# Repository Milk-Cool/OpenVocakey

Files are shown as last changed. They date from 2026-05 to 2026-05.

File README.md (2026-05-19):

# OpenVocakey
An open-source ESP32-based vocal synthesis keyboard

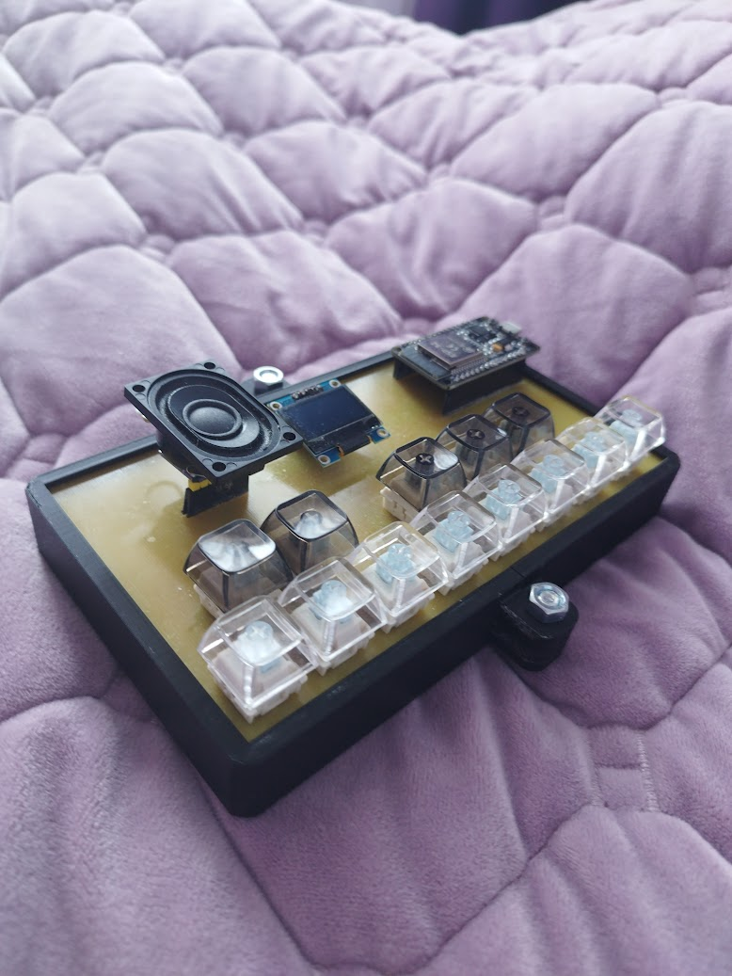
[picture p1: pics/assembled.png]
Assembled keyboard


## What is this?
This is exactly what it sounds like -- a DIY open-source keyboard capable of producing human-like speech in the form of singing. Yes, just like VOCALOID -- except it is live, so it would be closer to [Pocket Miku](https://youtu.be/Uk6hSK1DDR4) or the [VOCALOID Keytar](https://en.wikipedia.org/wiki/Vocaloid_Keyboard).

### What is this based on?
It uses [espeak-ng](https://github.com/espeak-ng/espeak-ng) at its core, with the wrapper being [BackgroundAudio](https://github.com/earlephilhower/BackgroundAudio) and the wrapper wrapper being `tts.cpp`. This means that the voices are actually very customizable! You can use formant settings to adjust the voice to your liking and then upload it to the device.

## How do I use it?
You can buy a [Cardputer](https://shop.m5stack.com/products/m5stack-cardputer-adv-version-esp32-s3) if you wanna check the project out, or make a keyboard of your own with the provided gerber and KiCad files. Then, you can upload songs and files using the [online tool](https://milk-cool.github.io/OpenVocakey/) (works best with Chromium-based browsers).

### Song format
A song is just a text file containing Japanese characters (hiragana or katakana but NOT kanji), with each syllable on its own line, for example:
```
き
ら
き
ら
ひ
か
る
```

You can also add ending syllables after a base syllable, separated by a comma (will not be stretched):
```
こ,い
```

> Note: you can input more than one syllable on one line, but then the vowel stretch won't work properly.

### Voice format
This is just an espeak-ng voice, but without the `pitch` and `language` fields (those are added automatically). See [the documentation for espeak-ng](https://github.com/espeak-ng/espeak-ng/blob/master/docs/voices.md) for specific instructions on how to create a voice.

### Assembling the board
If you decided to make your own keyboard, first of all, you'd have to order a two-layer PCB. This is because one of the traces (yes, just one!) is on the other side of the PCB. Then, once it arrives, you have to solder MX-Cherry style keyboard switches into the holes on the bottom of the board (and add keycaps to your liking) and solder on female 2.54mm headers everywhere else. Then, you can insert a 30-pin ESP32-WROOM board into the double headers (with the USB port facing outwards), an i2c SSD1306 display into the middle headers (facing inwards) and a MAX98357a i2s audio amplifier into the remaining headers (facing outwards; don't forget to connect a speaker!!). Also don't forget to solder on the 10K resistors for pull-up below the ESP32. Then you can print out the case (`case/`), slide the board inside and screw it down on the sides with M6x20 bolts. Then you'd have to upload the firmware to the ESP32 and you're done!!

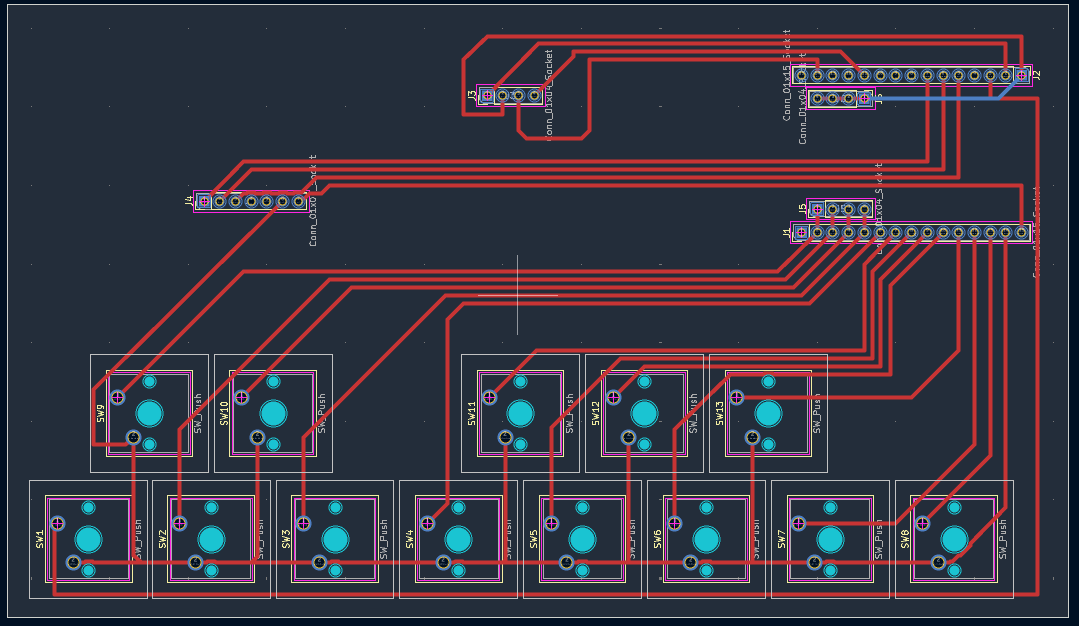
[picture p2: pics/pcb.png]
PCB


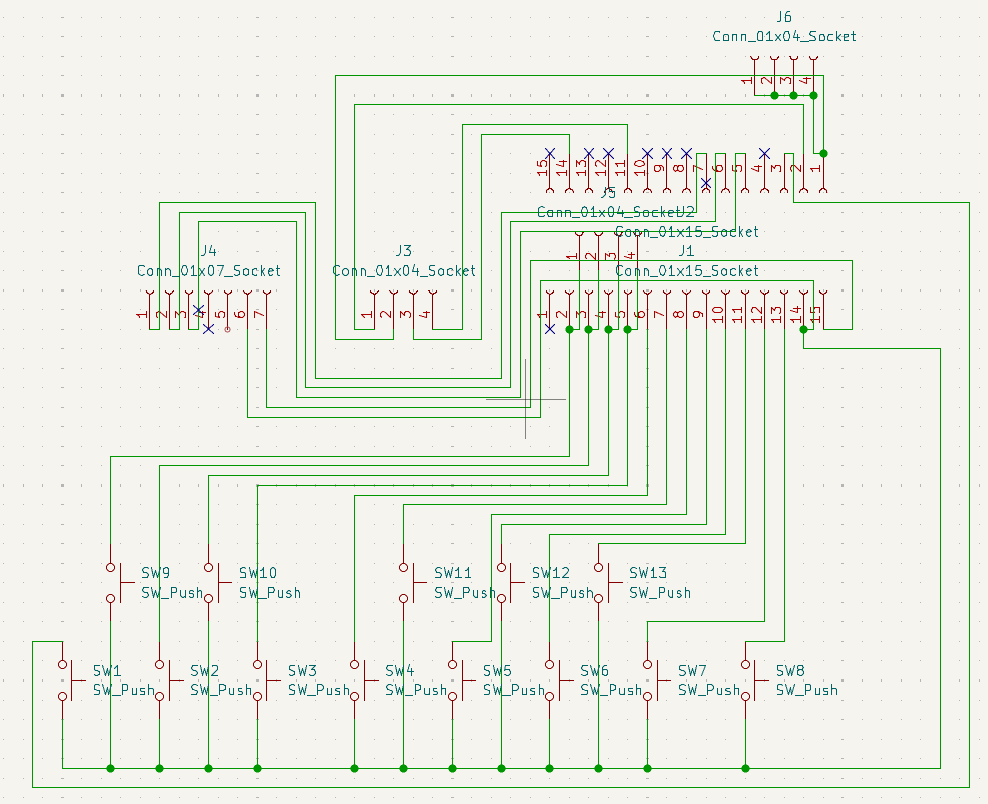
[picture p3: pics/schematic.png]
Schematic


> Note: see `bom.csv` for the Bill of Materials.

### Navigating the menus
You can press BOOT/G0 on your board to enter the menu. From there, you can press the two leftmost white buttons to move left or right, and the rightmost two white buttons for cancelling and confirming your actions (e. g. entering a submenu and then confirming the volume change using the rightmost button). You can also press G0 again to leave the menu.

Go on, play around with the menus and see what you can customize!!

> Note: most settings are discarded upon reboot.

### Using the website
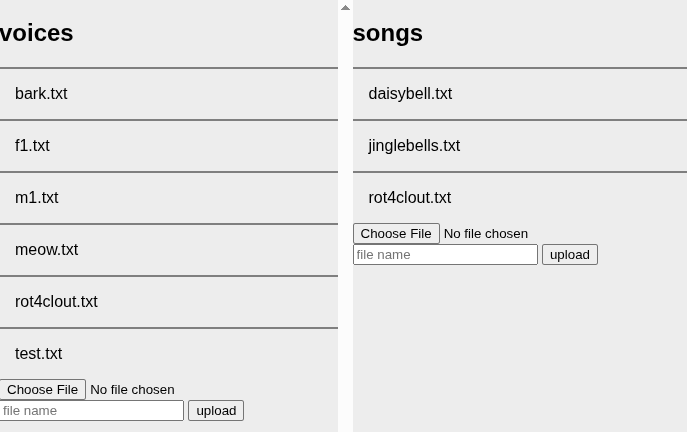
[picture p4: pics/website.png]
Website screenshot


You can use the [online tool](https://milk-cool.github.io/OpenVocakey/) to manage the files on your OpenVocakey. First, click "Connect" in the corner and select your board. Then, you can download the already existing files by clicking on them, or upload new files by first selecting the file, then giving it a name and then clicking "upload".

> Note: that **WILL** overwrite the file! Be careful.

## Why does this exist?
I was always fascinated by vocaloids and the two aforementioned products in paticular, hence I decided to make this. Those can be hard to get and rather unaffordable, especially in non-first-world countries, therefore I think people might find this useful.

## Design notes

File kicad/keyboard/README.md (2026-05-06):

Not my footprint!! See https://github.com/KiCad/kicad-footprints/blob/master/Button_Switch_Keyboard.pretty/SW_Cherry_MX_1.00u_PCB.kicad_mod

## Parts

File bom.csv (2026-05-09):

Product name | Product link | Product cost | Product amount | Notes
10 kOhm resistor | https://aliexpress.com/item/1005011886443911.html | $0.05 | 4 | Link leads to listing with 20 pieces available only. Price specified per unit; it is $0.91 to buy 20 pcs.
MX Cherry keyboard switches 1.00u | https://www.aliexpress.us/item/3256804049630074.html | $18.69 | 13 | Both 3-pin and 5-pin switches are acceptable.
White keycaps | https://www.aliexpress.us/item/3256808845306164.html | $1.76 | 8 | Link leads to listing with 20 pieces available only. Price specified per unit; it is $4.39 to buy 20 pcs.
White keycaps | https://www.aliexpress.us/item/3256808845306164.html | $1.10 | 5 | Link leads to listing with 20 pieces available only. Price specified per unit; it is $4.45 to buy 20 pcs.
ESP32 DevKitV1 | https://www.aliexpress.us/item/3256809960927549.html | $5.79 | 1
SSD1306 i2c OLED display | https://www.aliexpress.us/item/3256808099809825.html | $7.05 | 1 | Link leads to listing with multiple options. White i2c is recommended.
MAX98357A i2s audio amplifier | https://www.aliexpress.us/item/3256806817487911.html | $4.53 | 1
3W 4Ohm speaker | https://www.aliexpress.us/item/3256809207290559.html | $3.46 | 1
1x4 pin headers | https://nl.aliexpress.com/item/4001198421663.html | $0.17 | 1 | Link leads to listing with 10 pieces available only. Price specified per unit; it is $1.65 to buy 10 pcs.
1x7 pin headers | https://nl.aliexpress.com/item/4001198421663.html | $0.18 | 1 | Link leads to listing with 10 pieces available only. Price specified per unit; it is $1.79 to buy 10 pcs.
1x15 pin headers | https://nl.aliexpress.com/item/4001198421663.html | $0.21 | 2 | Link leads to listing with 10 pieces available only. Price specified per unit; it is $2.14 to buy 10 pcs.
Total |  | $42.99

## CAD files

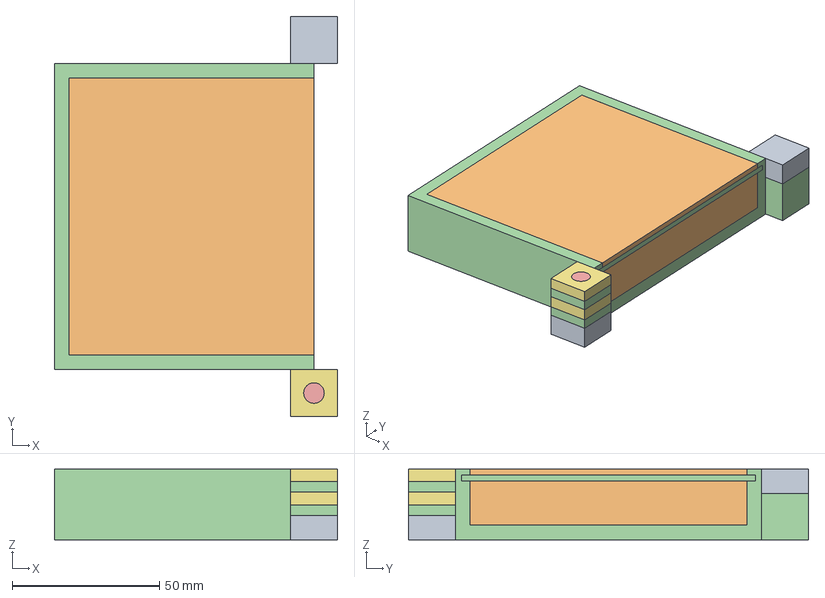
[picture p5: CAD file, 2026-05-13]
case/openvocakey.step
96.2 x 136.1 x 24.0 mm
X-axis x 3
XY-plane x 3
Sketch

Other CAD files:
case/openvocakey.FCStd
case/openvocakey.obj

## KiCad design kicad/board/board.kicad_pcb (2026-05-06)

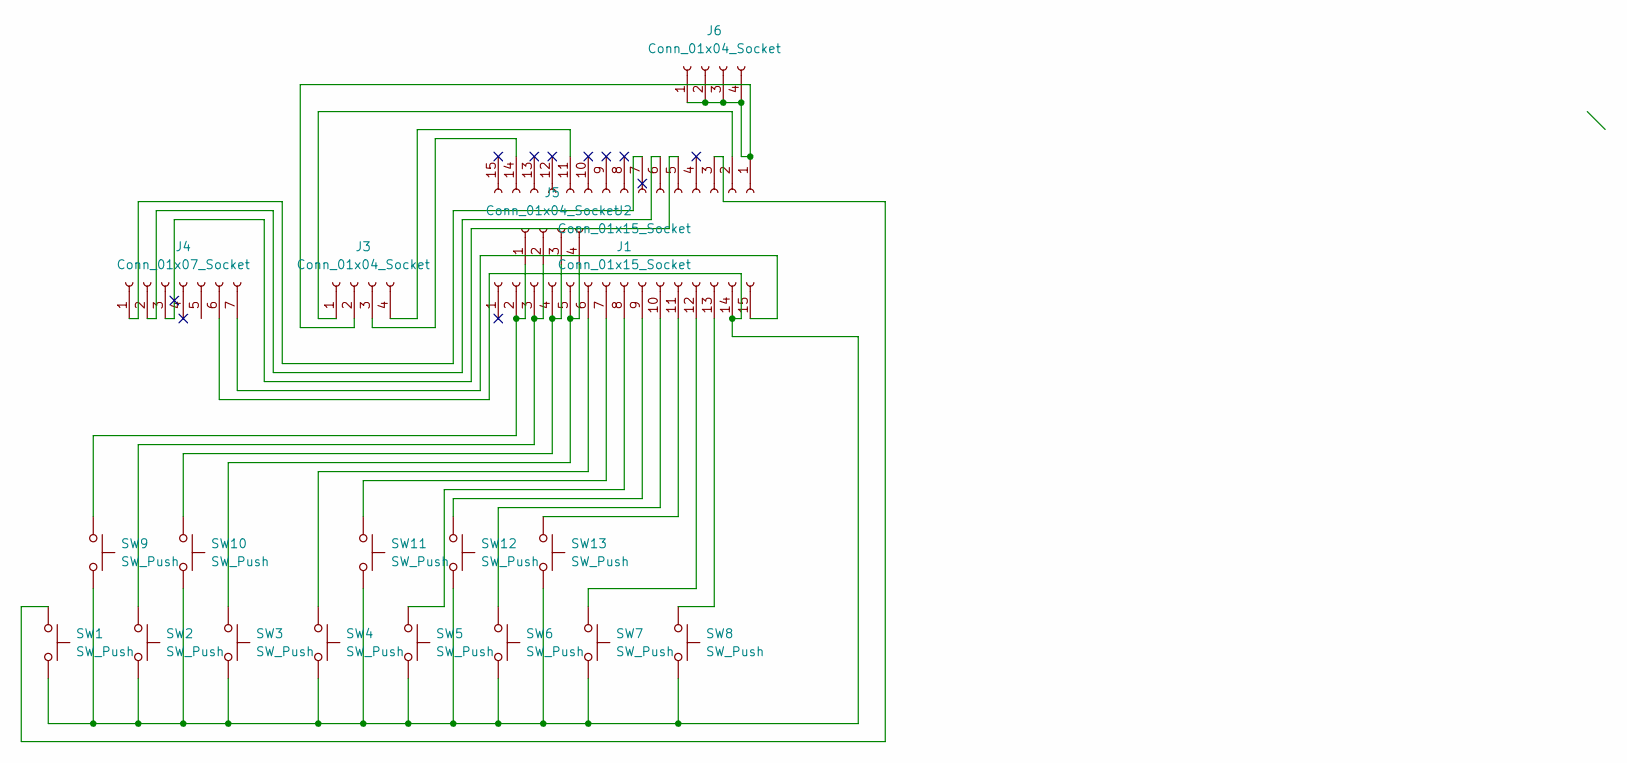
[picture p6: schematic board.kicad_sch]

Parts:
J1, J2: Conn_01x15_Socket; PinHeader_1x15_P2.54mm_Vertical
J3, J5, J6: Conn_01x04_Socket; PinHeader_1x04_P2.54mm_Vertical
J4: Conn_01x07_Socket; PinHeader_1x07_P2.54mm_Vertical
SW1, SW2, SW3, SW4, SW5, SW6, SW7, SW8, SW9, SW10, SW11, SW12, SW13: SW_Push; SW_Cherry_MX_1.00u_PCB

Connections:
unnamed: J1.2, J5.1, SW9.1
unnamed: J1.3, J5.2, SW2.1
unnamed: J1.4, J5.3, SW10.1
unnamed: J1.5, J5.4, SW3.1
unnamed: J1.6, SW4.1
unnamed: J1.7, SW11.1
unnamed: J1.8, SW5.1
unnamed: J1.9, SW12.1
unnamed: J1.10, SW6.1
unnamed: J1.11, SW13.1
unnamed: J1.12, SW7.1
unnamed: J1.13, SW8.1
unnamed: J1.14, J4.6, SW1.2, SW2.2, SW3.2, SW4.2, SW5.2, SW6.2, SW7.2, SW8.2, SW9.2, SW10.2, SW11.2, SW12.2, SW13.2
unnamed: J1.15, J4.7
unnamed: J2.1, J3.2, J6.1, J6.2, J6.3, J6.4
unnamed: J2.2, J3.1
unnamed: J2.3, SW1.1
unnamed: J2.5, J4.3
unnamed: J2.6, J4.2
unnamed: J2.7, J4.1
unnamed: J2.11, J3.4
unnamed: J2.14, J3.3

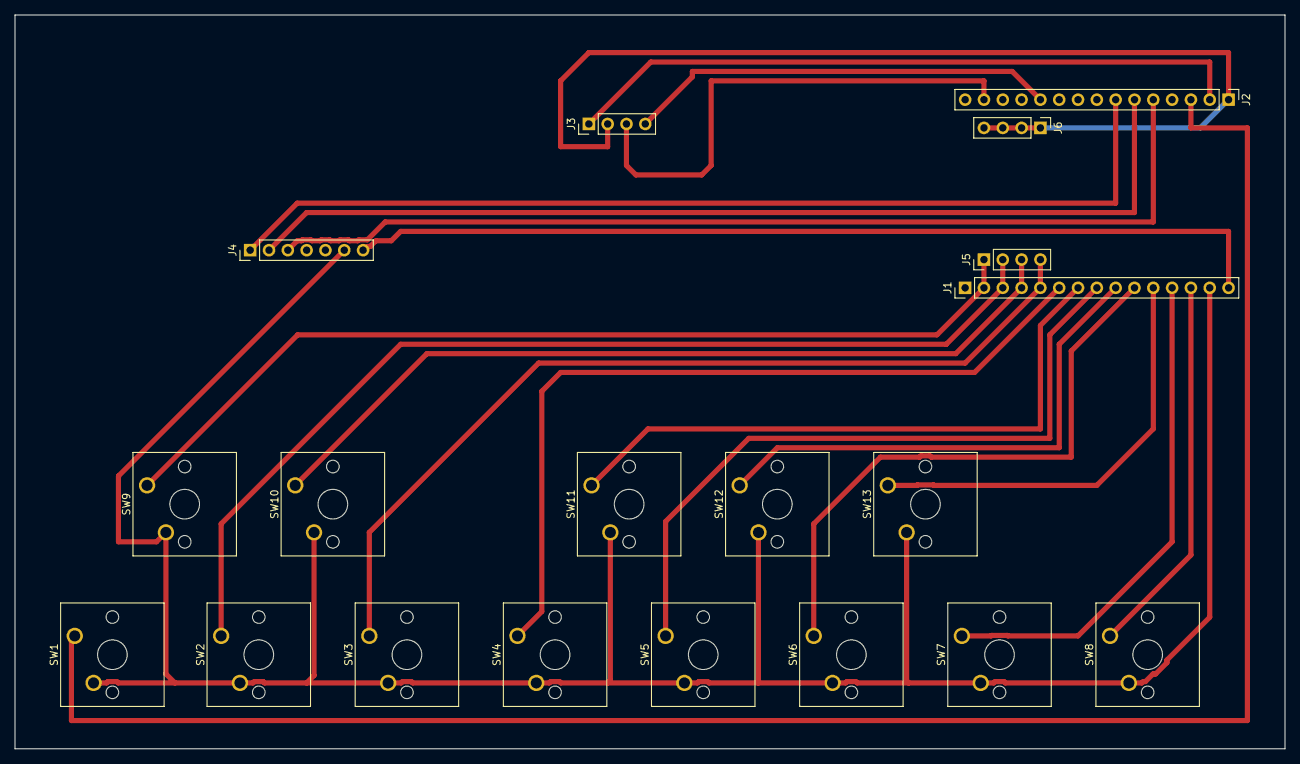
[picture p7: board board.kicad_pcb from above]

Board: 2 copper layers, 171.4 x 99.1 mm, 19 parts (0 on the bottom side), 22 nets.

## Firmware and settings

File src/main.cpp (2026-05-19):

#include <Arduino.h>
#ifdef CARDPUTER
#include <M5Cardputer.h>
#else
// #include "font.h"
#endif
#include "tts.h"
#include "pitch.h"
#include "cvt.h"
#include <LittleFS.h>
#include <vector>
#include <utility>
#include "input.h"
#include "gfx.h"

static unsigned i = 0;
static std::vector<std::pair<String, String>> g_song = {
    { "き", "" }, { "ら", "" }, { "き", "" }, { "ら", "" }, { "ひ", "" }, { "か", "" }, { "る", "" },
    { "お", "" }, { "そ", "" }, { "ら", "" }, { "の", "" }, { "ほ", "" }, { "し", "" }, { "よ", "" },
    { "ま", "" }, { "ば", "" }, { "た", "" }, { "き", "" }, { "し", "" }, { "て", "" }, { "は", "" },
    { "み", "" }, { "ん", "" }, { "な", "" }, { "を", "" }, { "み", "" }, { "て", "" }, { "る", "" },
    { "き", "" }, { "ら", "" }, { "き", "" }, { "ら", "" }, { "ひ", "" }, { "か", "" }, { "る", "" },
    { "お", "" }, { "そ", "" }, { "ら", "" }, { "の", "" }, { "ほ", "" }, { "し", "" }, { "よ", "" },
};

static uint8_t menu_mode = 0;
static uint8_t sel_option = 0;
static uint8_t config_option = 0;
static uint32_t file_idx = 0;
static int32_t num_val = 0;
#define CFG_SONG 1
#define CFG_VB 2
#define CFG_WPM 3
#define CFG_STRETCH 4
#define CFG_VOLUME 5
#define CFG_TRANSPOSE 6
#define CFG_MAX CFG_TRANSPOSE

void setup() {
    Serial.begin(115200);
#ifdef CARDPUTER
    auto cfg = M5.config();
    M5Cardputer.begin(cfg);
    M5Cardputer.Speaker.begin();
#endif
    gfx_init();
    // M5Cardputer.Display.println("ws");
    // M5Cardputer.Display.println(M5Cardputer.Speaker.config().pin_ws);
    // M5Cardputer.Display.println("data_out");
    // M5Cardputer.Display.println(M5Cardputer.Speaker.config().pin_data_out);
    // M5Cardputer.Display.println("bck");
    // M5Cardputer.Display.println(M5Cardputer.Speaker.config().pin_bck);
    // M5Cardputer.Display.println("mck");
    // M5Cardputer.Display.println(M5Cardputer.Speaker.config().pin_mck);
    input_init();
    tts_init();
    tts_load_voice("", 440);
    tts_set_wpm(200);
    LittleFS.begin(true);
    if(!LittleFS.exists("/songs")) LittleFS.mkdir("/songs");
    if(!LittleFS.exists("/vbs")) LittleFS.mkdir("/vbs");

    Serial.print("> ");
    Serial.flush();

    pinMode(0, INPUT_PULLUP);
}
static SynthKey pressed = KEY_NONE;
static void next_syl(float pitch) {
    tts_set_pitch(pitch_calc(440, pitch));
    String cvtd = cvt_syl(g_song[i++ % g_song.size()].first);
    tts_play(cvtd.c_str());
}
uint64_t last_screen_upd = 0;
static String inp = "";
static std::vector<String> parse_args(String& raw) {
    std::vector<String> out;
    String cur;
    for(char c : raw) {
        if(c == ' ') {
            if(cur != "") out.push_back(cur);
            cur = "";
        } else cur += c;
    }
    if(cur != "") out.push_back(cur);
    return out;
}
static void print_and_close_dir(File& f) {
    while(true) {
        String fname = f.getNextFileName();
        if(fname == "") break;
        Serial.println(fname);
    }
    f.close();
}
static void write_from_serial_and_close_file(File& f) {
    String in = "";
    // blocking
    while(true) {
        if(!Serial.available()) continue;
        char c = Serial.read();
        Serial.print(c);
        if(c == '\r') continue;
        in += c;
        if(in.endsWith("EOF\n")) break;
    }
    in = in.substring(0, in.length() - 4);
    f.write((uint8_t*)in.c_str(), in.length());
    f.close();
}
static void load_song(String str) {
    String cur = "";
    i = 0;
    g_song.clear();
    for(char c : str) {
        if(c == '\r') continue;
        if(c == '\n') {
            if(cur != "") {
                int idx = cur.indexOf(',');
                if(idx == -1) g_song.push_back(std::pair<String, String>(cur, ""));
                else g_song.push_back(std::pair<String, String>(cur.substring(0, idx), cur.substring(idx + 1)));
            }
            cur = "";
        } else cur += c;
    }
    if(cur != "") {
        int idx = cur.indexOf(',');
        if(idx == -1) g_song.push_back(std::pair<String, String>(cur, ""));
        else g_song.push_back(std::pair<String, String>(cur.substring(0, idx), cur.substring(idx + 1)));
    }
}
static bool boot_pressed = false;
void loop() {
    // CLI
    while(Serial.available()) {
        char c = Serial.read();
        Serial.print(c);
        Serial.flush();
        if(c == '\r') continue;
        if(c == '\n') {
            auto vec = parse_args(inp);
            if(vec.size() == 0) {}
            else if(vec[0] == "help") {
                Serial.println("help - print this message");
                Serial.println("v_list - list installed voicebanks");
                Serial.println("v_get <voice> - get voicebank by filename");
                Serial.println("v_set <voice> - save voicebank until \"EOF\"");
                Serial.println("v_sel <voice> - select voicebank to use");
                Serial.println("s_list - list saved songs");
                Serial.println("s_get <song> - get song by filename");
                Serial.println("s_set <song> - save song until \"EOF\"");
                Serial.println("s_sel <song> - select song to sing");
                Serial.println("wpm <wpm> - set the wpm for the espeak engine, useful for shortening consonants");
                Serial.println("stretch <cnt_vowels> - set the vowel stretch, high values may produce lag");
            } else if(vec[0] == "v_list") {
                File vbs = LittleFS.open("/vbs");
                print_and_close_dir(vbs);
            } else if(vec[0] == "s_list") {
                File songs = LittleFS.open("/songs");
                print_and_close_dir(songs);
            } else if(vec[0] == "v_get" && vec.size() >= 2) {
                File vb = LittleFS.open("/vbs/" + vec[1]);
                Serial.println(vb.readString());
                vb.close();
            } else if(vec[0] == "s_get" && vec.size() >= 2) {
                File song = LittleFS.open("/songs/" + vec[1]);
                Serial.println(song.readString());
                song.close();
            } else if(vec[0] == "v_set" && vec.size() >= 2) {
                File vb = LittleFS.open("/vbs/" + vec[1], "w");
                write_from_serial_and_close_file(vb);
            } else if(vec[0] == "s_set" && vec.size() >= 2) {
                File song = LittleFS.open("/songs/" + vec[1], "w");
                write_from_serial_and_close_file(song);
            } else if(vec[0] == "v_sel" && vec.size() >= 2) {
                File vb = LittleFS.open("/vbs/" + vec[1]);
                tts_load_voice(vb.readString(), 440);
                vb.close();
            } else if(vec[0] == "s_sel" && vec.size() >= 2) {
                File song = LittleFS.open("/songs/" + vec[1]);
                load_song(song.readString());
                song.close();
            } else if(vec[0] == "wpm" && vec.size() >= 2) {
                tts_set_wpm(vec[1].toInt());
            } else if(vec[0] == "stretch" && vec.size() >= 2) {
                set_stretch(vec[1].toInt());
            } else {
                Serial.println("Invalid command or arguments");
            }
            inp = "";
            Serial.print("> ");
            Serial.flush();
        } else inp += c;
    }

    if(!digitalRead(0) && !boot_pressed) {
        if(menu_mode == 0) {
            menu_mode = 1;
            sel_option = 0;
        } else menu_mode = 0;
        boot_pressed = true;
    } else if(digitalRead(0)) boot_pressed = false;

    // Update state (STATE 0)
    if(menu_mode == 0) {
        input_upd();
        uint64_t now = millis();
        if(now - last_screen_upd > 100) {
            gfx_start_render();
            String t = "";
            for(int I = i % g_song.size(); I < i % g_song.size() + 7 && I < g_song.size(); I++)
                t += g_song[I].first + g_song[I].second;
            gfx_set_jp(true);
#ifdef CARDPUTER
            gfx_print(2, 2, t + "                     ");
#else
            gfx_print(2, 32, t + "                     ");
#endif
            last_screen_upd = now;
            gfx_end_render();
        }
        SynthKey k;
        int j = 0;
        if(pressed != KEY_NONE && !input_pressed(pressed)) {
            tts_stop();
            if(g_song[(i - 1) % g_song.size()].second.length() > 0) tts_play(g_song[(i - 1) % g_song.size()].second.c_str());
            pressed = KEY_NONE;
        }
        if(pressed == KEY_NONE) while((k = all_keys[j++]) != KEY_NONE) if(input_pressed(k)) {
            pressed = k;
            next_syl(get_freq(k));
        }
    // Update state (STATE 1)
    } else if(menu_mode == 1) {
        input_upd();
        uint64_t now = millis();
        if(now - last_screen_upd > 100) {
            gfx_start_render();
            String opt = sel_option == 0
                ? "restart song"
                : sel_option == 1
                ? "change song"
                : sel_option == 2
                ? "change voice"
                : sel_option == 3
                ? "change speed"
                : sel_option == 4
                ? "change stretch"
                : sel_option == 5
                ? "change volume"
                : "transpose";
            gfx_set_jp(false);
#ifdef CARDPUTER
            gfx_print(2, 2, opt);
#else
            gfx_print(2, 16, opt);
#endif
            last_screen_upd = now;
            gfx_end_render();
        }
        if(pressed != KEY_NONE && !input_pressed(pressed)) {
            pressed = KEY_NONE;
        } else if(pressed == KEY_NONE) {
            if(input_pressed(KEY_C4)) {
                pressed = KEY_C4;
                if(sel_option == 0) sel_option = CFG_MAX;
                else sel_option--;
            } else if(input_pressed(KEY_D4)) {
                pressed = KEY_D4;
                if(sel_option == CFG_MAX) sel_option = 0;
                else sel_option++;
            } else if(input_pressed(KEY_B4)) {
                pressed = KEY_B4;
                menu_mode = 0;
            } else if(input_pressed(KEY_C5)) {
                pressed = KEY_C5;
                if(sel_option == 0) {
                    menu_mode = 0;
                    i = 0;
                } else {
                    menu_mode = 2;
                    config_option = sel_option;
                    file_idx = 0;
                    if(config_option == CFG_WPM) num_val = tts_get_wpm();
                    else if(config_option == CFG_STRETCH) num_val = get_stretch();
                    else if(config_option == CFG_VOLUME) num_val = tts_get_vol() * 100;
                    else if(config_option == CFG_TRANSPOSE) num_val = get_transpose();
                }
            }
        }
    // Update state (STATE 2, FILE SELECT)
    } else if(menu_mode == 2 && (config_option == CFG_SONG || config_option == CFG_VB)) {
        input_upd();
        uint64_t now = millis();
        if(now - last_screen_upd > 100) {
            gfx_start_render();
            String p = config_option == CFG_SONG ? "/songs" : "/vbs";
            File dir = LittleFS.open(p);
            String f = dir.getNextFileName();
            for(uint32_t i = 0; i < file_idx; i++) f = dir.getNextFileName();
            if(f == "") {
                file_idx = 0;
                dir.close();
                dir = LittleFS.open(p);
                f = dir.getNextFileName();
                if(f == "") {
                    menu_mode = 0;
                    dir.close();
                    return;
                }
            }
            gfx_set_jp(false);
#ifdef CARDPUTER
            gfx_print(2, 2, config_option == CFG_SONG ? f.substring(7) : f.substring(5));
#else
            gfx_print(2, 16, config_option == CFG_SONG ? f.substring(7) : f.substring(5));
#endif
            gfx_end_render();
            last_screen_upd = now;
            dir.close();
        }
        if(pressed != KEY_NONE && !input_pressed(pressed)) {
            pressed = KEY_NONE;
        } else if(pressed == KEY_NONE) {
            if(input_pressed(KEY_C4)) {
                pressed = KEY_C4;
                if(file_idx != 0) file_idx--;
            } else if(input_pressed(KEY_D4)) {
                pressed = KEY_D4;
                file_idx++;
            } else if(input_pressed(KEY_B4)) {
                pressed = KEY_B4;
                menu_mode = 1;
            } else if(input_pressed(KEY_C5)) {
                pressed = KEY_C5;
                String dname = config_option == CFG_SONG ? "/songs" : "/vbs";
                menu_mode = 0;
                File dir = LittleFS.open(dname);
                String f = dir.getNextFileName();
                for(uint32_t i = 0; i < file_idx; i++) f = dir.getNextFileName();
                dir.close();
                File f2 = LittleFS.open(f);
                if(config_option == CFG_SONG) load_song(f2.readString());
                else tts_load_voice(f2.readString(), 440);
                f2.close();
                if(config_option == CFG_SONG) i = 0;
            }
        }
    // Update state (STATE 2, NUMERIC SETTINGS)
    } else if(menu_mode == 2 && (config_option == CFG_WPM || config_option == CFG_STRETCH || config_option == CFG_VOLUME || config_option == CFG_TRANSPOSE)) {
        input_upd();
        uint64_t now = millis();
        if(now - last_screen_upd > 100) {
            gfx_start_render();
            gfx_set_jp(false);
#ifdef CARDPUTER
            gfx_print(2, 2, String(num_val));
#else
            gfx_print(2, 16, String(num_val));
#endif
            gfx_end_render();
            last_screen_upd = now;
        }
        if(pressed != KEY_NONE && !input_pressed(pressed)) {
            pressed = KEY_NONE;
        } else if(pressed == KEY_NONE) {
            if(input_pressed(KEY_C4)) {
                pressed = KEY_C4;
                if(config_option == CFG_STRETCH && num_val > 0) num_val -= 5;
                else if(config_option == CFG_WPM && num_val > 10) num_val -= 10;
                else if(config_option == CFG_VOLUME && num_val > 0) num_val -= 10;
                else if(config_option == CFG_TRANSPOSE && num_val > -3) num_val--;
            } else if(input_pressed(KEY_D4)) {
                pressed = KEY_D4;
                if(config_option == CFG_STRETCH && num_val < 200) num_val += 5;
                else if(config_option == CFG_WPM && num_val < 500) num_val += 10;
                else if(config_option == CFG_VOLUME && num_val < 100) num_val += 10;
                else if(config_option == CFG_TRANSPOSE && num_val < 8) num_val++;
            } else if(input_pressed(KEY_B4)) {
                pressed = KEY_B4;
                menu_mode = 1;
            } else if(input_pressed(KEY_C5)) {
                pressed = KEY_C5;
                if(config_option == CFG_STRETCH) set_stretch(num_val);
                else if(config_option == CFG_WPM) tts_set_wpm(num_val);
                else if(config_option == CFG_VOLUME) tts_set_vol((float)num_val / 100);
                else if(config_option == CFG_TRANSPOSE) set_transpose(num_val);
                menu_mode = 0;
            }
        }
    }
}

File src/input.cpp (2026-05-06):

#include "input.h"
#ifdef CARDPUTER
#include <M5Cardputer.h>
#else
#include <Arduino.h>
#include <map>
#endif

#define DEBOUNCE 10

SynthKey all_keys[] = {
    KEY_C4,
    KEY_CS4,
    KEY_D4,
    KEY_DS4,
    KEY_E4,
    KEY_F4,
    KEY_FS4,
    KEY_G4,
    KEY_GS4,
    KEY_A4,
    KEY_AS4,
    KEY_B4,
    KEY_C5,
    KEY_NONE
};
#ifndef CARDPUTER
typedef struct {
    uint64_t t;
    bool pressed;
} Debounce;
std::map<SynthKey, Debounce> debounce = {
    { KEY_C4, { 0, false } },
    { KEY_CS4, { 0, false } },
    { KEY_D4, { 0, false } },
    { KEY_DS4, { 0, false } },
    { KEY_E4, { 0, false } },
    { KEY_F4, { 0, false } },
    { KEY_FS4, { 0, false } },
    { KEY_G4, { 0, false } },
    { KEY_GS4, { 0, false } },
    { KEY_A4, { 0, false } },
    { KEY_AS4, { 0, false } },
    { KEY_B4, { 0, false } },
    { KEY_C5, { 0, false } },
};
#endif

void input_init() {
#ifndef CARDPUTER
    pinMode(15, INPUT_PULLUP);
    pinMode(36, INPUT);
    pinMode(39, INPUT);
    pinMode(34, INPUT);
    pinMode(35, INPUT);
    pinMode(32, INPUT_PULLUP);
    pinMode(33, INPUT_PULLUP);
    pinMode(25, INPUT_PULLUP);
    pinMode(26, INPUT_PULLUP);
    pinMode(27, INPUT_PULLUP);
    pinMode(14, INPUT_PULLUP);
    pinMode(12, INPUT_PULLUP);
    pinMode(13, INPUT_PULLUP);
#endif
}

static int8_t transpose = 0;
void set_transpose(int8_t l_transpose) {
    transpose = l_transpose;
}
int8_t get_transpose() {
    return transpose;
}

float freqs[] = {
    // -3
    220.00,
    233.08,
    246.94,
    //
    261.63,
    277.18,
    293.67,
    311.13,
    329.63,
    349.23,
    369.99,
    392.00,
    415.30,
    440.00,
    466.16,
    493.88,
    523.25,
    //
    554.37,
    587.33,
    622.25,
    698.46,
    739.99,
    783.99,
    830.61,
    880.00,
    // +8
};

float get_freq(SynthKey key) {
    if(key == KEY_C4) return freqs[3 + transpose];
    if(key == KEY_CS4) return freqs[4 + transpose];
    if(key == KEY_D4) return freqs[5 + transpose];
    if(key == KEY_DS4) return freqs[6 + transpose];
    if(key == KEY_E4) return freqs[7 + transpose];
    if(key == KEY_F4) return freqs[8 + transpose];
    if(key == KEY_FS4) return freqs[9 + transpose];
    if(key == KEY_G4) return freqs[10 + transpose];
    if(key == KEY_GS4) return freqs[11 + transpose];
    if(key == KEY_A4) return freqs[12 + transpose];
    if(key == KEY_AS4) return freqs[13 + transpose];
    if(key == KEY_B4) return freqs[14 + transpose];
    if(key == KEY_C5) return freqs[15 + transpose];
    return freqs[12 + transpose];
}
void input_upd() {
#ifdef CARDPUTER
    M5Cardputer.Keyboard.updateKeyList();
    M5Cardputer.Keyboard.updateKeysState();
#endif
}
#ifdef CARDPUTER
#define KEY1(k, o) if(key == o) return M5Cardputer.Keyboard.isKeyPressed(k);
bool input_pressed(SynthKey key) {
    KEY1('a', KEY_C4)
    KEY1('w', KEY_CS4)
    KEY1('s', KEY_D4)
    KEY1('e', KEY_DS4)
    KEY1('d', KEY_E4)
    KEY1('f', KEY_F4)
    KEY1('t', KEY_FS4)
    KEY1('g', KEY_G4)
    KEY1('y', KEY_GS4)
    KEY1('h', KEY_A4)
    KEY1('u', KEY_AS4)
    KEY1('j', KEY_B4)
    KEY1('k', KEY_C5)
    return false;
}
#else
#define KEY2(p, o) if(key == o) { if(now - debounce[o].t < DEBOUNCE) { return debounce[o].pressed; } debounce[o].t = now; int v = !digitalRead(p); debounce[o].pressed = v; return v; }
bool input_pressed(SynthKey key) {
    uint64_t now = millis();
    // Serial.printf("%d %hhu\n", 15, !digitalRead(15));
    // Serial.printf("%d %hu\n", 36, analogRead(36));
    // Serial.printf("%d %hu\n", 39, analogRead(39));
    // Serial.printf("%d %hu\n", 34, analogRead(34));
    // Serial.printf("%d %hu\n", 35, analogRead(35));
    // Serial.printf("%d %hhu\n", 32, !digitalRead(32));
    // Serial.printf("%d %hhu\n", 33, !digitalRead(33));
    // Serial.printf("%d %hhu\n", 25, !digitalRead(25));
    // Serial.printf("%d %hhu\n", 26, !digitalRead(26));
    // Serial.printf("%d %hhu\n", 27, !digitalRead(27));
    // Serial.printf("%d %hhu\n", 14, !digitalRead(14));
    // Serial.printf("%d %hhu\n", 12, !digitalRead(12));
    // Serial.printf("%d %hhu\n", 13, !digitalRead(13));
    KEY2(15, KEY_C4)
    KEY2(36, KEY_CS4)
    KEY2(39, KEY_D4)
    KEY2(34, KEY_DS4)
    KEY2(35, KEY_E4)
    KEY2(32, KEY_F4)
    KEY2(33, KEY_FS4)
    KEY2(25, KEY_G4)
    KEY2(26, KEY_GS4)
    KEY2(27, KEY_A4)
    KEY2(14, KEY_AS4)
    KEY2(12, KEY_B4)
    KEY2(13, KEY_C5)
    return false;
}
#endif

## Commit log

2026-04-30 YAAYA i figured out the pitch
2026-04-30 switch to japanese only
2026-05-01 a potential slight performance fix
    [main.cpp]
2026-05-02 reset button
2026-05-05 A LOT of fixes + custom board support
    [input.cpp, main.cpp]
2026-05-05 config menu!! (only for custom board)
2026-05-06 update base case
2026-05-06 add kicad project & gerber files
    [board-B_Cu.gbr, board-B_Mask.gbr, board-B_Paste.gbr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]
2026-05-06 add resistors to README
2026-05-06 Added BOM
    [bom.csv]
2026-05-06 upload zine page & pcb pic
2026-05-09 update bom with headers
    [bom.csv]
2026-05-10 add schematic to readme
2026-05-10 add zipped gerbers
2026-05-13 upload 3d model of the case & update zine and readme
    [openvocakey.FCStd, openvocakey.obj]
2026-05-13 add .step file
    [openvocakey.step]
2026-05-13 update readme's assembly instructions
